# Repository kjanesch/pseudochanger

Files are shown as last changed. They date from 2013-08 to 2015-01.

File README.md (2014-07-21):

pseudochanger
=============
A project that aims to add an auxiliary input to head units that use the Panasonic variant of the Alpine MBus protocol.

Alpine MBus is a bidirectional one-wire serial interface used for communication between audio head units and peripherals like CD players, CD changers, and tape decks. A period for each bit is 3 ms, and low/high bits are indicated by how long the line is held low. Low for the first 600us indicates a 1, low for 1800 us indicates a 0. Data is a multiple of four bits, and a four-bit check follows the packet, an XOR of all the other 4-bit chunks.

The Panasonic variant uses different ping and ACK codes, sends some data at different times, and does what looks like type detection by sending out a cycle of codes. The included library reflects these differences.

This project was developed specifically for the 2002 Subaru WRX head unit, model CQ-EF7260A, and should work with other Panasonic head units that have the same 16-pin connector on the back, as also found in some Mazdas and Hondas.

This project contains:
 - Arduino MBusPanasonic library
   - Timing-driven bus interface
   - Sends static timestamp of Disc 1, Track 1, Time A:0A to indicate aux input 
 - Example implementation (pseudochanger)
   - Uses the Teensy branch of [finsprings/arduinaap](https://github.com/finsprings/arduinaap/tree/teensy) for the iPod Accessory Protocol interface.
 - Circuit and PCB diagrams
   - V1 is the handmade, free-handed version
   - V2 is the (incomplete) PCB of V1 with minor tweaks
   - V2.5 is a completely respun, integrated design
     - Built-in Atmega 32U4 (or 16U4 depending on code space needs)
     - Onboard switching regulator to generate 5V supply from +12V and accessory on/off
     - Smaller (0805/0603) SMT components
     - Ethernet jack for iPod connector
     - Op-amp based switch to make it solid state

TODO: 
 - Library:
   - Interrupt-driven approach to receiving and sending MBus data
   - Integrated polling routine to extract button presses
   - Fix issues with generating timestamps
   - Add a short example that doesn't keep state, switch between inputs, or control iPods (fewer I/Os, less setup, smaller code, no dependencies)
 - Implementation: 
   - Sort out why iPod interface doesn't work (Hardware? Software?)
 - EAGLE files:
   - Finish V2.5 PCB and BOM, construct boards IRL and test

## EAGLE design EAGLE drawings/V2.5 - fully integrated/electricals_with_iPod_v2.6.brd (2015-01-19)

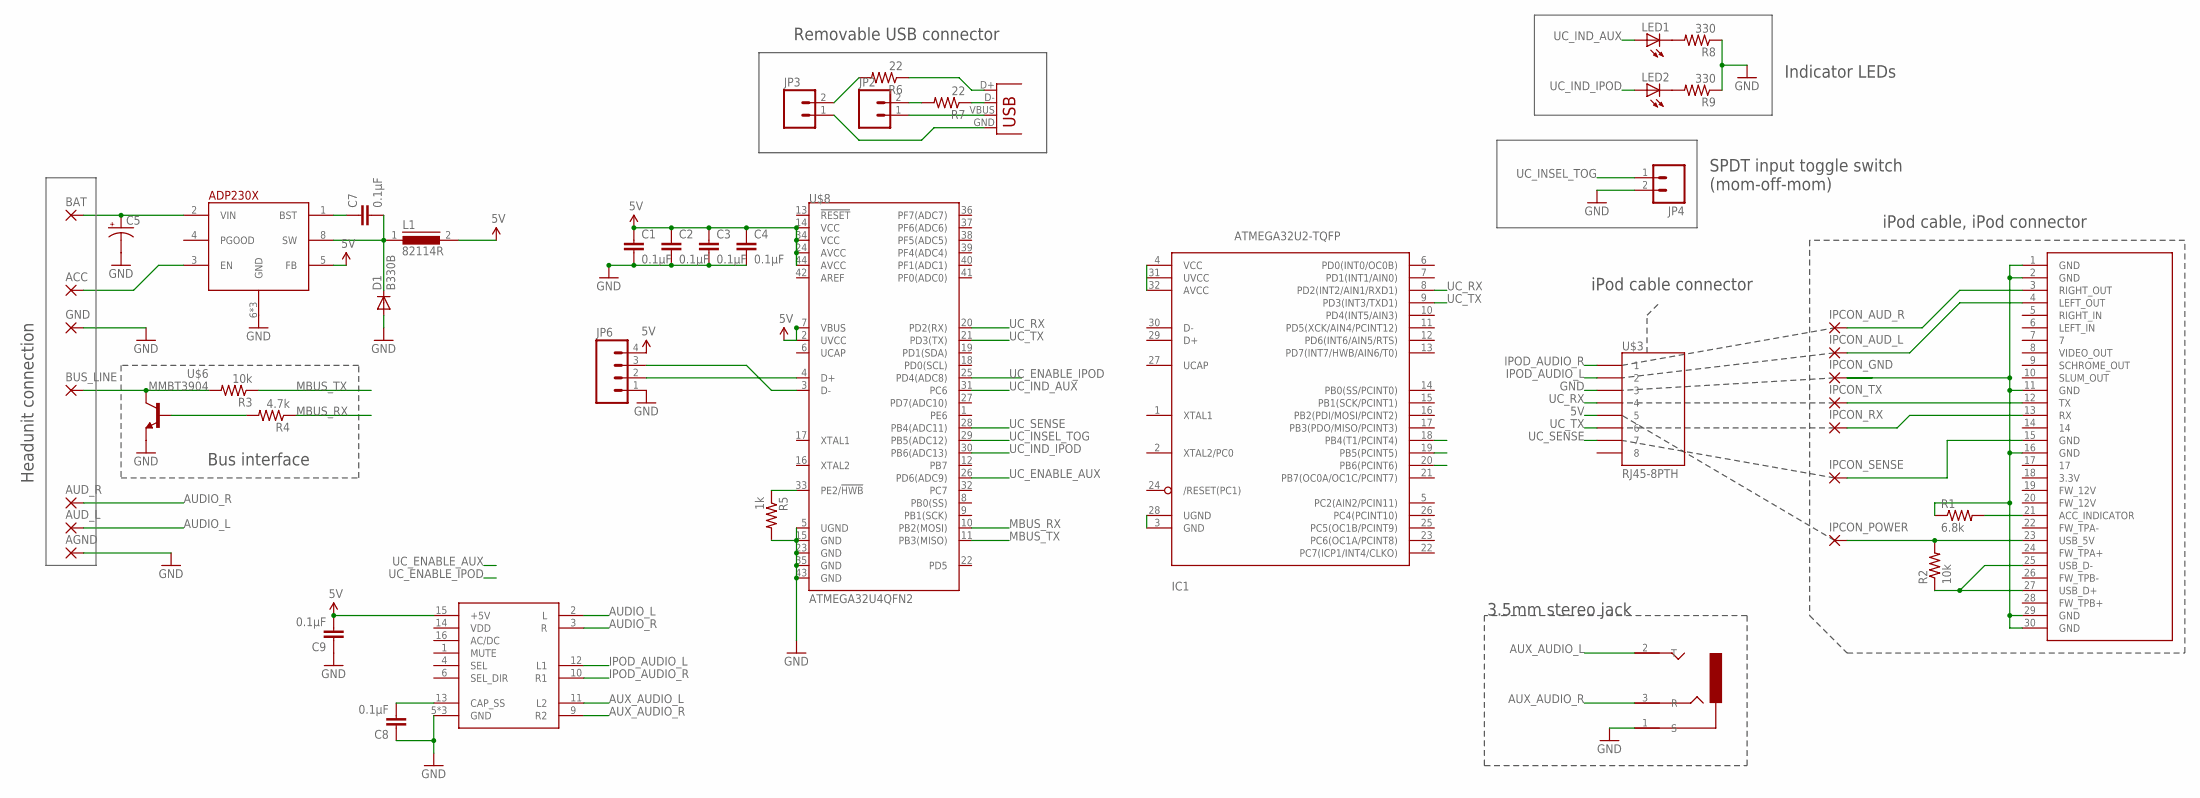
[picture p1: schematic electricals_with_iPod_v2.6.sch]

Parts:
ACC: 1,6/0,9
AGND: 1,6/0,9
AUD_L: 1,6/0,9
AUD_R: 1,6/0,9
BAT: 2,54/1,1
BUS_LINE: 1,6/0,9
C1, C2, C3, C4, C7, C8, C9: 0.1µF; 0603-CAP
C5: CAP_POLPTH2; CPOL-RADIAL-10UF-25V
D1: B330B; SMA-DIODE_ALT
GND: 2,54/1,1
IC1: ATMEGA32U2-TQFP; TQFP32-08
IPCON_AUD_L: 1,6/0,9
IPCON_AUD_R: 1,6/0,9
IPCON_GND: 1,6/0,9
IPCON_POWER: 1,6/0,9
IPCON_RX: 1,6/0,9
IPCON_SENSE: 1,6/0,9
IPCON_TX: 1,6/0,9
JP1: USBSMD; USB-MINIB
JP2, JP3: M02POGO_PIN_HOLES_ONLY; 1X02_PP_HOLES_ONLY
JP4: M02LOCK; 1X02_LOCK
JP6: M04PTH; 1X04
L1: 82114R
LED1, LED2: LED0603; LED-0603
R1: 6.8k; 0603-RES
R2, R3: 10k; 0603-RES
R4: 4.7k; 0603-RES
R5: 1k; 0603-RES
R6, R7: 22; 0603-RES
R8, R9: 330; 0603-RES
U$1: IPOD_CONNECTOR_MALE; IPOD_MALE_CONNECTOR
U$3: RJ45-8PTH; RJ45-8
U$5: ADP230X; SO8-THERM
U$6: MMBT3904; SOT23-3
U$7: STEREO_JACK_SJ1-353XNG3NG; 3.5MM_SJ1-353XNG
U$8: ATMEGA32U4QFN2; SPARKFUN-DIGITALIC_QFN-44-NOPAD
U$11: ISL54405IRTZ; QFN-16

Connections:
5V: C1.1, C2.1, C3.1, C4.1, C9.2, JP6.4, L1.2, U$3.5, U$5.5 (FB), U$8.2 (UVCC), U$8.7 (VBUS), U$8.14 (VCC), U$8.24 (AVCC), U$8.34 (VCC), U$8.44 (AVCC), U$11.15 (+5V)
AUDIO_L: AUD_L.1, U$11.2 (L)
AUDIO_R: AUD_R.1, U$11.3 (R)
AUX_AUDIO_L: U$7.2 (T), U$11.11 (L2)
AUX_AUDIO_R: U$7.3 (R), U$11.9 (R2)
GND: AGND.1, C1.2, C2.2, C3.2, C4.2, C5.2 (-), C8.1, C9.1, D1.A, GND.1, JP4.2, JP6.1, R5.2, R8.1, R9.1, U$3.3, U$5.6 (GND), U$5.7 (GND), U$5.PAD (GND), U$6.2 (E), U$7.1 (S), U$8.5 (UGND), U$8.15 (GND), U$8.23 (GND), U$8.35 (GND), U$8.43 (GND), U$11.5 (GND), U$11.7 (GND), U$11.8 (GND)
IPOD_AUDIO_L: U$3.2, U$11.12 (L1)
IPOD_AUDIO_R: U$3.1, U$11.10 (R1)
IP_GND: IPCON_GND.1, R1.1, U$1.1 (GND), U$1.2 (GND), U$1.11 (GND), U$1.16 (GND), U$1.29 (GND), U$1.30 (GND)
MBUS_RX: R4.1, U$8.10 (PB2(MOSI))
MBUS_TX: R3.1, U$8.11 (PB3(MISO))
unnamed: ACC.1, U$5.3 (EN)
unnamed: BAT.1, C5.1 (+), U$5.2 (VIN)
unnamed: C7.2, D1.C, L1.1, U$5.8 (SW)
unnamed: IPCON_POWER.1, R2.2, U$1.23 (USB_5V)
unnamed: C7.1, U$5.1 (BST)
unnamed: IPCON_SENSE.1, U$1.15 (GND)
unnamed: IPCON_RX.1, U$1.13 (RX)
unnamed: IPCON_TX.1, U$1.12 (TX)
unnamed: IPCON_AUD_R.1, U$1.3 (RIGHT_OUT)
unnamed: IPCON_AUD_L.1, U$1.4 (LEFT_OUT)
unnamed: R2.1, U$1.25 (USB_D-), U$1.27 (USB_D+)
unnamed: C8.2, U$11.13 (CAP_SS)
unnamed: R1.2, U$1.21 (ACC_INDICATOR)
unnamed: R5.1, U$8.33 (PE2/!HWB)
unnamed: LED1.C, R8.2
unnamed: LED2.C, R9.2
unnamed: IC1.3 (GND), IC1.28 (UGND)
unnamed: IC1.4 (VCC), IC1.32 (AVCC)
unnamed: BUS_LINE.1, R3.2, U$6.3 (C)
unnamed: R4.2, U$6.1 (B)
unnamed: JP1.D+, R6.1
unnamed: JP1.D-, R7.1
UC_ENABLE_AUX: U$8.26 (PD6(ADC9))
UC_ENABLE_IPOD: U$8.25 (PD4(ADC8))
UC_IND_AUX: LED1.A, U$8.31 (PC6)
UC_IND_IPOD: LED2.A, U$8.30 (PB6(ADC13))
UC_INSEL_TOG: JP4.1, U$8.29 (PB5(ADC12))
UC_RX: IC1.8 (PD2(INT2/AIN1/RXD1)), U$3.4, U$8.20 (PD2(RX))
UC_SENSE: U$3.7, U$8.28 (PB4(ADC11))
UC_TX: IC1.9 (PD3(INT3/TXD1)), U$3.6, U$8.21 (PD3(TX))
USB_BOB_D+: JP3.2, R6.2
USB_BOB_D-: JP2.2, R7.2
USB_BOB_GND: JP1.GND, JP3.1
USB_BOB_VBUS: JP1.VBUS, JP2.1
USB_D+: JP6.2, U$8.4 (D+)
USB_D-: JP6.3, U$8.3 (D-)

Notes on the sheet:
Bus interface
SPDT input toggle switch (mom-off-mom)
3.5mm stereo jack
Indicator LEDs
iPod cable, iPod connector
iPod cable connector
Headunit connection
Removable USB connector

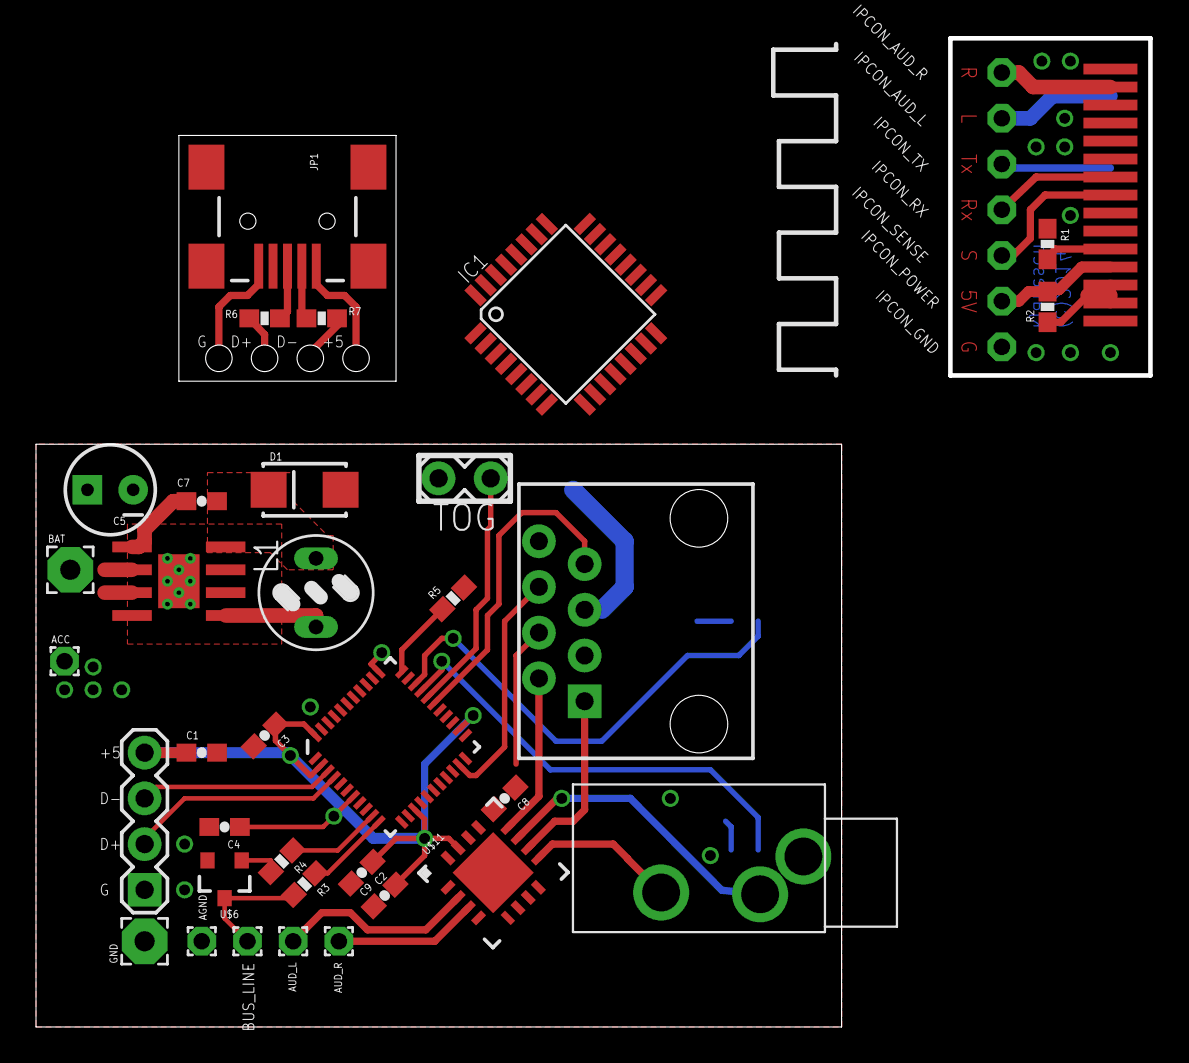
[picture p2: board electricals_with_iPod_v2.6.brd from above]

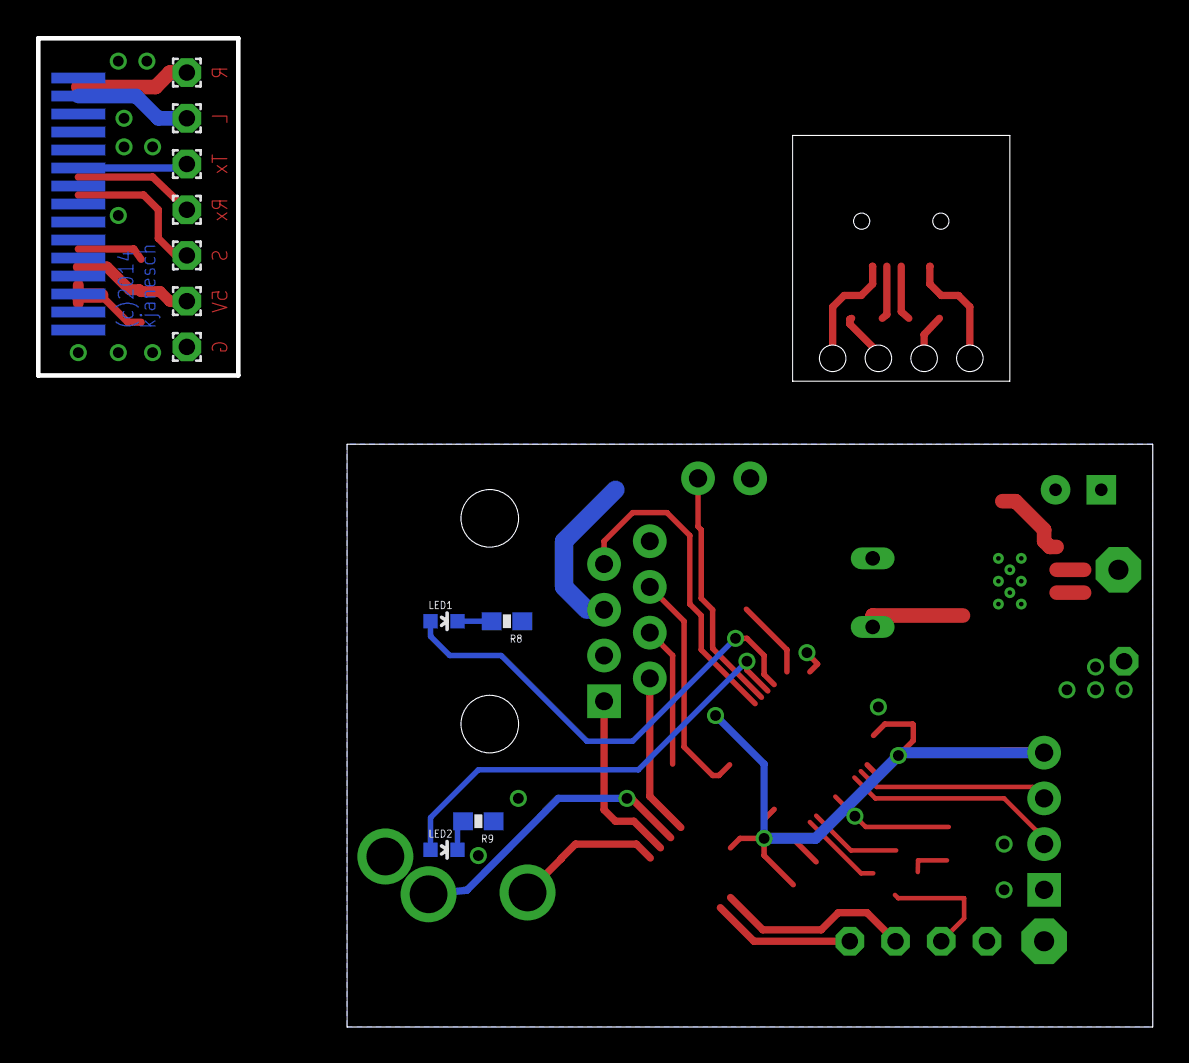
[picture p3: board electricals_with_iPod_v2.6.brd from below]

Board: 2 copper layers, 61.9 x 54.9 mm, 48 parts (12 on the bottom side), 45 nets.

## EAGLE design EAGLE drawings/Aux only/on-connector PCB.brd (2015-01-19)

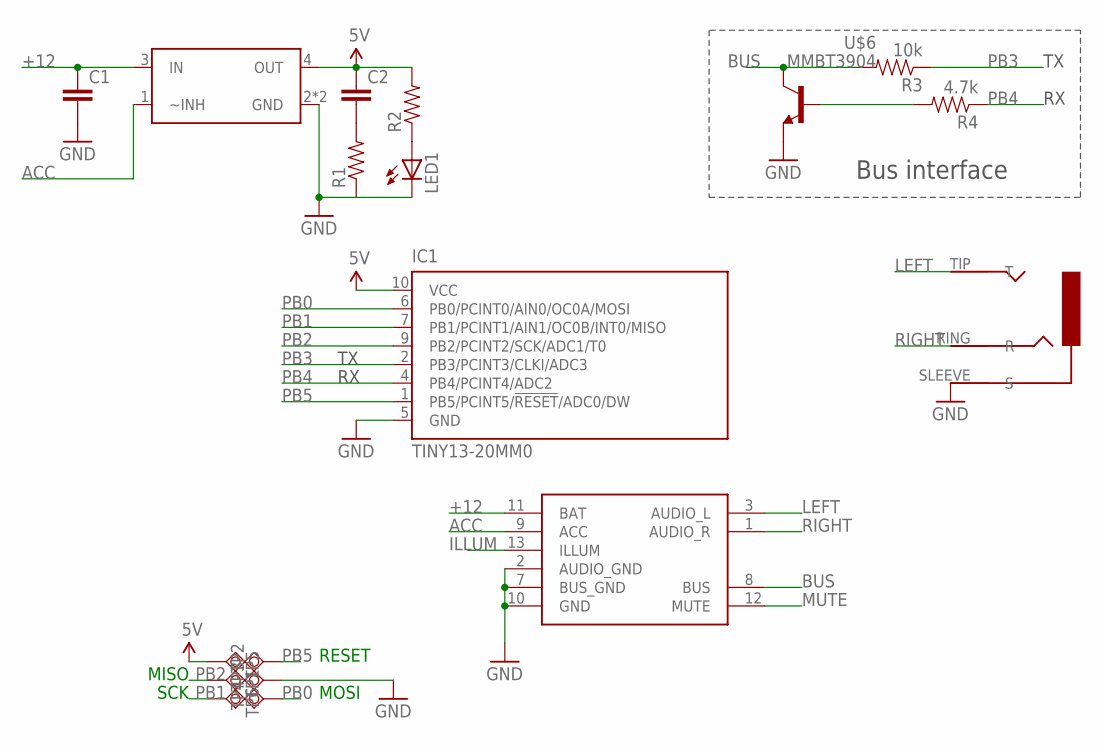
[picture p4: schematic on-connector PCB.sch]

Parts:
C1, C2: CAP0603-CAP; 0603-CAP
IC1: TINY13-20MM0; 10M1
LED1: LED0603; LED-0603
R1, R2: RESISTOR0603-RES; 0603-RES
R3: 10k; 0805
R4: 4.7k; 0805
TP1, TP2, TP3, TP4, TP6: TPSQTP07R; TP07R
TP5: TPSQTP07SQ; TP07SQ
U$1: PANASONIC_CN702_BACKBOARD; 040_MLCII_BACK_CN702
U$2: STEREO_JACK_SJ_352X; AUDIO-JACK-3.5MM-SMD
U$6: MMBT3904; SOT23-3
U$7: IFX20001; PG-SCT595-5

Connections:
5V: C2.1, IC1.10 (VCC), R2.2, TP5.TP, U$7.4 (OUT)
+12: C1.1, U$1.11 (BAT), U$7.3 (IN)
ACC: U$1.9 (ACC), U$7.1 (~INH)
BUS: R3.2, U$1.8 (BUS), U$6.3 (C)
GND: C1.2, IC1.5 (GND), IC1.11 (GND), LED1.C, R1.1, TP3.TP, U$1.2 (AUDIO_GND), U$1.7 (BUS_GND), U$1.10 (GND), U$2.SLEEVE (S), U$6.2 (E), U$7.2 (GND), U$7.5 (GND)
ILLUM: U$1.13 (ILLUM)
LEFT: U$1.3 (AUDIO_L), U$2.TIP (T)
MUTE: U$1.12 (MUTE)
unnamed: C2.2, R1.2
unnamed: LED1.A, R2.1
unnamed: R4.2, U$6.1 (B)
PB0: IC1.6 (PB0/PCINT0/AIN0/OC0A/MOSI), TP4.TP
PB1: IC1.7 (PB1/PCINT1/AIN1/OC0B/INT0/MISO), TP6.TP
PB2: IC1.9 (PB2/PCINT2/SCK/ADC1/T0), TP1.TP
PB3: IC1.2 (PB3/PCINT3/CLKI/ADC3), R3.1
PB4: IC1.4 (PB4/PCINT4/ADC2), R4.1
PB5: IC1.1 (PB5/PCINT5/!RESET!/ADC0/DW), TP2.TP
RIGHT: U$1.1 (AUDIO_R), U$2.RING (R)

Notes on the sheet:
Bus interface
MOSI
MISO
SCK
RESET

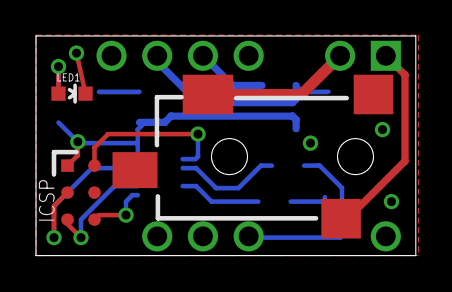
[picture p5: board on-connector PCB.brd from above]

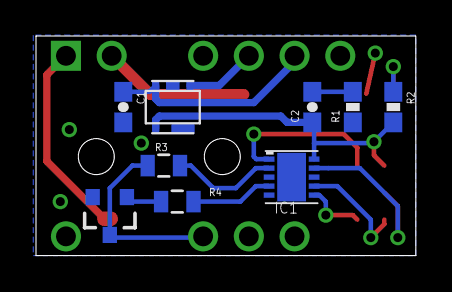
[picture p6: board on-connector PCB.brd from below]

Board: 2 copper layers, 21.1 x 12.2 mm, 18 parts (9 on the bottom side), 16 nets.

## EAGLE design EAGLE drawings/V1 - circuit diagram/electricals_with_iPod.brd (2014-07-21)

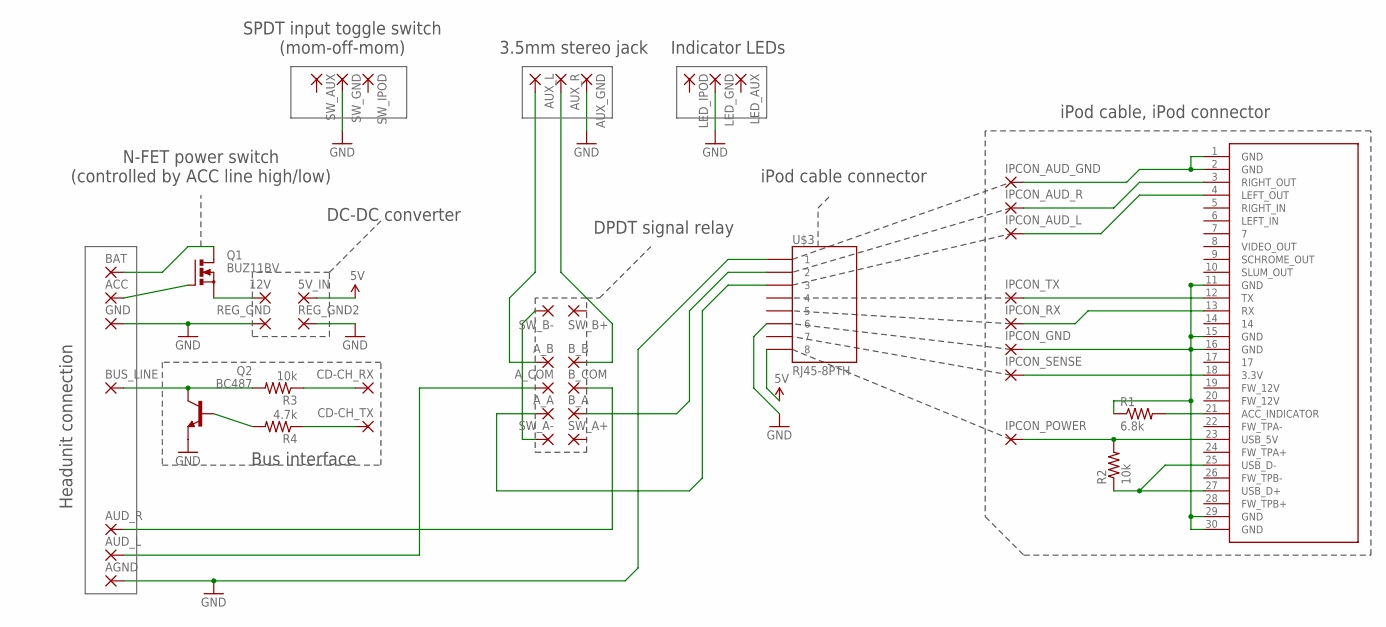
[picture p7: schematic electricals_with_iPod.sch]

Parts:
5V_IN, 12V: 2,54/1,1
ACC: 1,6/0,9
AGND: 1,6/0,9
AUD_L: 1,6/0,9
AUD_R: 1,6/0,9
AUX_GND: 1,6/0,9
AUX_L: 1,6/0,9
AUX_R: 1,6/0,9
A_A: 1,6/0,9
A_B: 1,6/0,9
A_COM: 1,6/0,9
BAT: 2,54/1,1
BUS_LINE: 1,6/0,9
B_A: 1,6/0,9
B_B: 1,6/0,9
B_COM: 1,6/0,9
CD-CH_RX: 1,6/0,9
CD-CH_TX: 1,6/0,9
GND: 2,54/1,1
IPCON_AUD_GND: 1,6/0,9
IPCON_AUD_L: 1,6/0,9
IPCON_AUD_R: 1,6/0,9
IPCON_GND: 1,6/0,9
IPCON_POWER: 1,6/0,9
IPCON_RX: 1,6/0,9
IPCON_SENSE: 1,6/0,9
IPCON_TX: 1,6/0,9
LED_AUX: 1,6/0,9
LED_GND: 1,6/0,9
LED_IPOD: 1,6/0,9
Q1: BUZ11BV; TO220BV
Q2: BC487; TO92-EBC
R1: 6.8k; 1206
R2, R3: 10k; 1206
R4: 4.7k; 1206
REG_GND, REG_GND2: 2,54/1,1
SW_A+: 1,6/0,9
SW_A-: 1,6/0,9
SW_AUX: 1,6/0,9
SW_B+: 1,6/0,9
SW_B-: 1,6/0,9
SW_GND: 1,6/0,9
SW_IPOD: 1,6/0,9
U$1: IPOD_CONNECTOR_MALE; IPOD_MALE_CONNECTOR
U$3: RJ45-8PTH; RJ45-8

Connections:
5V: 5V_IN.1, U$3.8
GND: AGND.1, AUX_GND.1, GND.1, LED_GND.1, Q2.E, REG_GND.1, REG_GND2.1, SW_GND.1, U$3.1, U$3.6
unnamed: ACC.1, Q1.G
unnamed: BAT.1, Q1.D
unnamed: 12V.1, Q1.S
unnamed: IPCON_POWER.1, R2.2, U$1.23 (USB_5V)
unnamed: IPCON_AUD_GND.1, U$1.1 (GND), U$1.2 (GND)
unnamed: IPCON_SENSE.1, U$1.18 (3.3V)
unnamed: IPCON_RX.1, U$1.13 (RX)
unnamed: IPCON_TX.1, U$1.12 (TX)
unnamed: IPCON_AUD_R.1, U$1.3 (RIGHT_OUT)
unnamed: IPCON_AUD_L.1, U$1.4 (LEFT_OUT)
unnamed: R2.1, U$1.25 (USB_D-), U$1.27 (USB_D+)
unnamed: IPCON_GND.1, R1.1, U$1.11 (GND), U$1.15 (GND), U$1.16 (GND), U$1.29 (GND), U$1.30 (GND)
unnamed: R1.2, U$1.21 (ACC_INDICATOR)
unnamed: SW_A-.1, SW_B-.1
unnamed: AUD_L.1, A_COM.1
unnamed: AUD_R.1, B_COM.1
unnamed: AUX_L.1, A_B.1
unnamed: AUX_R.1, B_B.1
unnamed: BUS_LINE.1, Q2.C, R3.2
unnamed: Q2.B, R4.2
unnamed: CD-CH_RX.1, R3.1
unnamed: CD-CH_TX.1, R4.1
unnamed: B_A.1, U$3.2
unnamed: A_A.1, U$3.3

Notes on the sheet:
Bus interface
N-FET power switch (controlled by ACC line high/low)
DC-DC converter
SPDT input toggle switch (mom-off-mom)
3.5mm stereo jack
Indicator LEDs
iPod cable, iPod connector
iPod cable connector
DPDT signal relay
Headunit connection

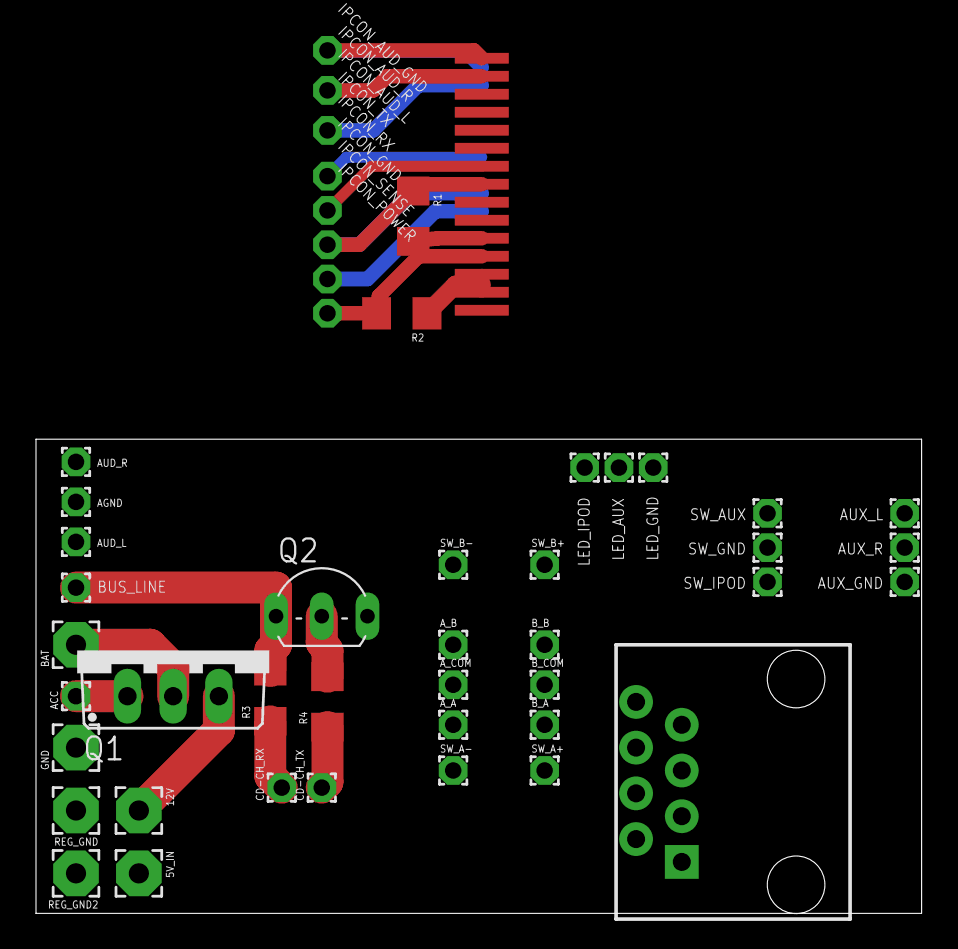
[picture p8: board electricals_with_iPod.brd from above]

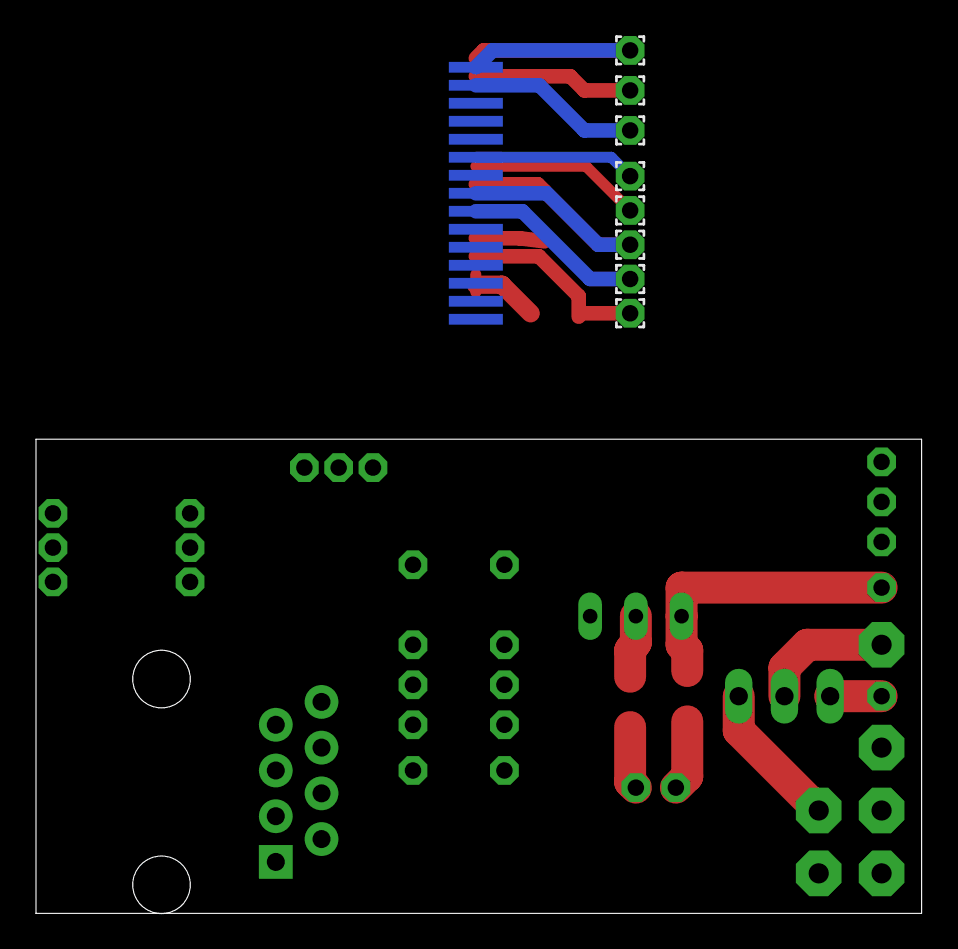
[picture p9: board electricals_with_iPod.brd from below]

Board: 2 copper layers, 49.2 x 26.3 mm, 48 parts (9 on the bottom side), 26 nets.

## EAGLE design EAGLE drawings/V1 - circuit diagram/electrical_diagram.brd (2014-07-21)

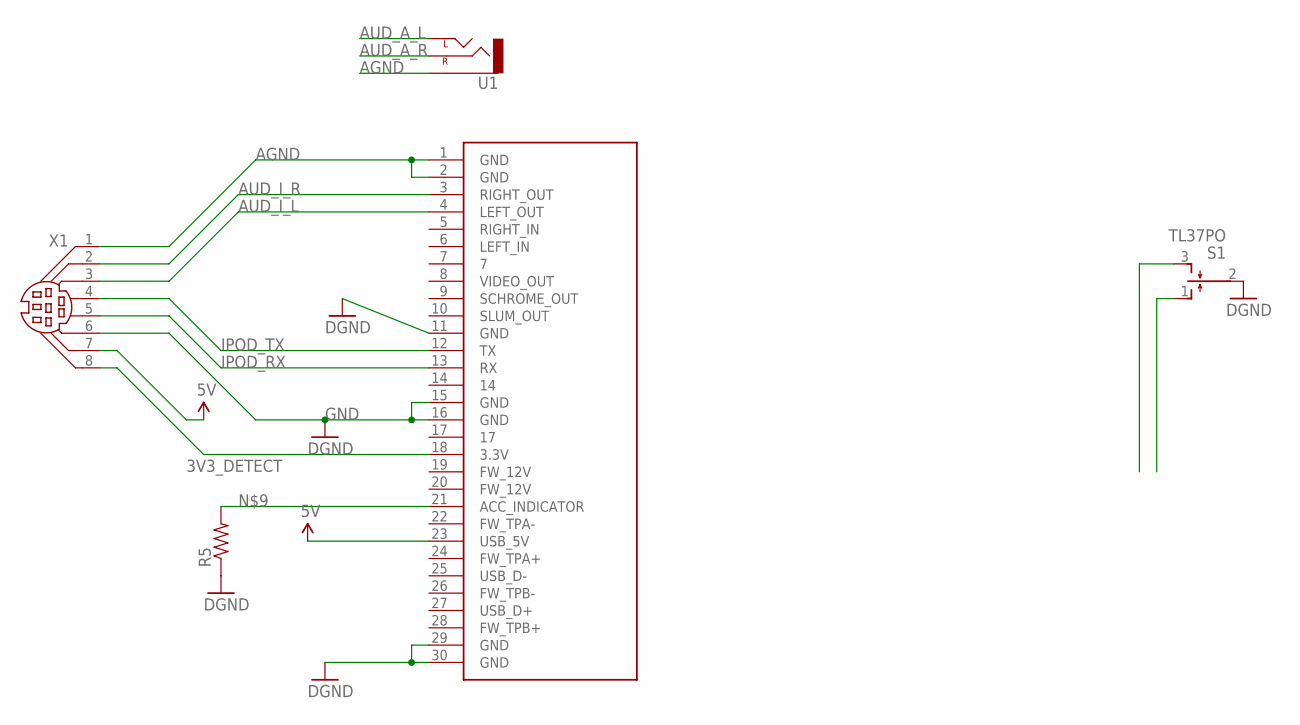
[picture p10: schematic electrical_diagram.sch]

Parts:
R5: RESISTOR0805-RES; 0805
S1: TL37PO; TL3XPO
U1: AUDIO-JACKSMD2; AUDIO-JACK-3.5MM-SMD
U$1: IPOD_CONNECTOR_MALE; IPOD_MALE_CONNECTOR
X1: MDIN08K

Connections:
3V3_DETECT: U$1.18 (3.3V), X1.8
5V: U$1.23 (USB_5V), X1.7
AGND: U1.SLEEVE, U$1.1 (GND), U$1.2 (GND), X1.1
AUD_A_L: U1.TIP (LEFT)
AUD_A_R: U1.RING (RIGHT)
AUD_I_L: U$1.4 (LEFT_OUT), X1.3
AUD_I_R: U$1.3 (RIGHT_OUT), X1.2
GND: R5.1, S1.2, U$1.11 (GND), U$1.15 (GND), U$1.16 (GND), U$1.29 (GND), U$1.30 (GND), X1.6
IPOD_RX: U$1.13 (RX), X1.5
IPOD_TX: U$1.12 (TX), X1.4
unnamed: R5.2, U$1.21 (ACC_INDICATOR)

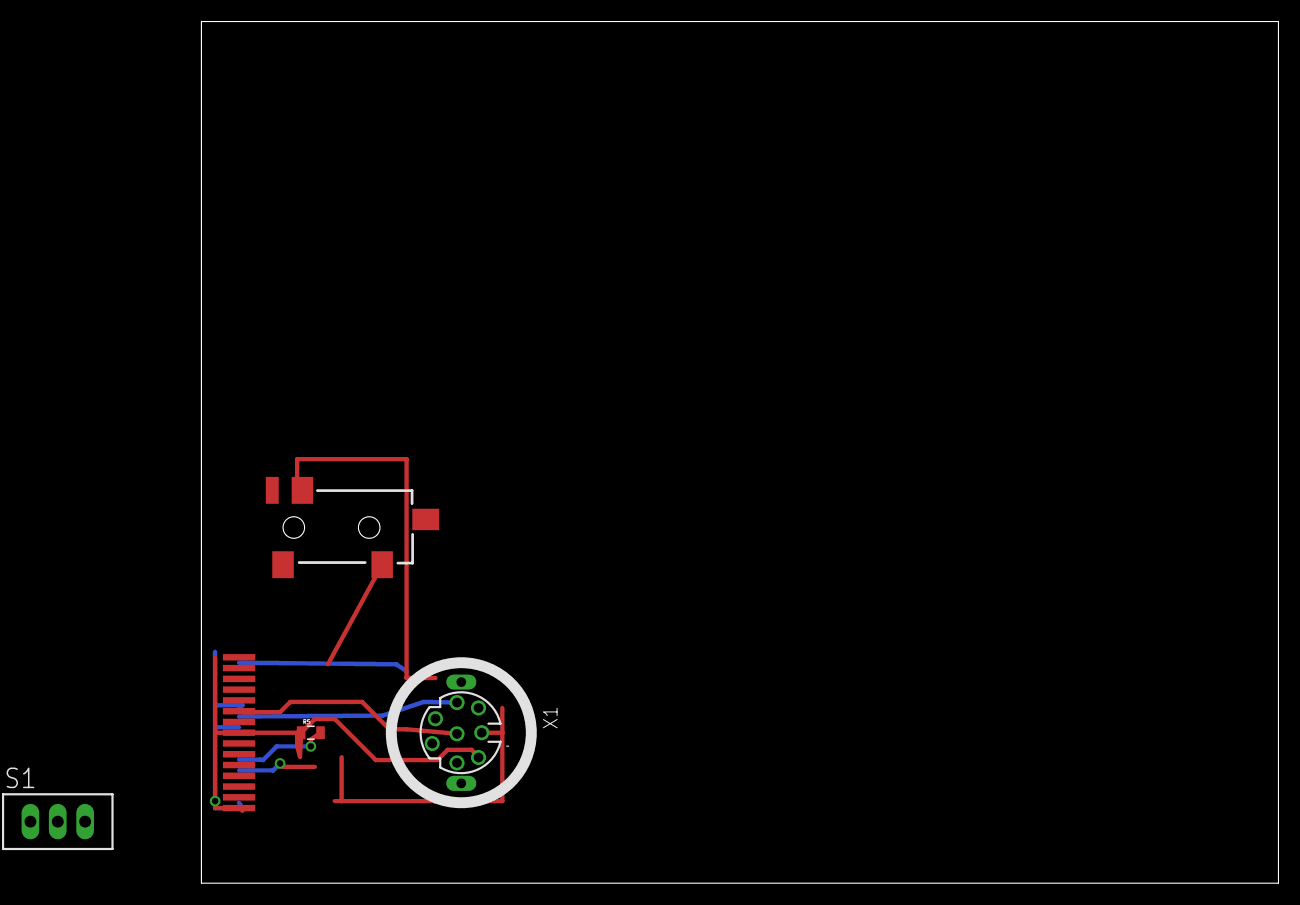
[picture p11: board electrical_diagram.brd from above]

Board: 2 copper layers, 100.0 x 80.0 mm, 5 parts (0 on the bottom side), 9 nets.

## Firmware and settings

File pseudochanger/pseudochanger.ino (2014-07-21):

#include <AdvancedRemote.h>
#include <MBusPanasonic.h>

//#define IPOD_SERIAL_DEBUG
#define DEBUG_MODE
//#define DISABLE_RELAY

//playback state definitions
#define IPOD_ACTIVE 1
#define AUX_ACTIVE  2
#define MBUS_DELAY 7

#define mBusIn  PIN_D1
#define mBusOut PIN_D0

//pin definitions
static const byte SENSE_IPOD  = PIN_F4;
static const byte LED_AUX     = PIN_C6;
static const byte LED_IPOD    = PIN_C7;
static const byte RELAY_AUX   = PIN_B0;
static const byte RELAY_IPOD  = PIN_B1;
static const byte TOGGLE_AUX  = PIN_D5;
static const byte TOGGLE_IPOD = PIN_D4;

byte activeInput;

boolean ipodAvailable = false;

MBus mBus(mBusIn, mBusOut);

//HardwareSerial uart = HardwareSerial();
AdvancedRemote ipod = AdvancedRemote(Serial1);

byte playbackStatus = STOPPED;
boolean updateDisplay = false;

unsigned long plistindex = 1;
unsigned long trackindex = 1;

unsigned long playtime = 0;
unsigned long plistcount = 0;
unsigned long trackcount = 0;

uint64_t mbusMsg = 0ULL;
uint64_t nextUpdate = 0;
uint64_t prevPing   = 0;

uint32_t tmp = 0;

/// iPod AdvancedRemote callbacks ////////////////////////////////////
void shuffleModeHandler(AdvancedRemote::ShuffleMode mode){
  switch(mode){
  case AdvancedRemote::SHUFFLE_MODE_OFF:
    Serial.println("shuffle off");
    playbackStatus &= ~SHUFFLE_MASK;
    break;
  case AdvancedRemote::SHUFFLE_MODE_SONGS:
    Serial.println("shuffle songs");
    playbackStatus =  ((~SHUFFLE_MASK)&playbackStatus)| SHUFFLE_SONGS;
    break;
  case AdvancedRemote::SHUFFLE_MODE_ALBUMS:
    Serial.println("shuffle off");
    playbackStatus =  ((~SHUFFLE_MASK)&playbackStatus)| SHUFFLE_ALBUMS;
    break;
  }
}

void repeatModeHandler(AdvancedRemote::RepeatMode mode){
  switch(mode){
  case AdvancedRemote::REPEAT_MODE_OFF:
    Serial.println("repeat off");
    playbackStatus &= ~REPEAT_MASK;
    break;
  case AdvancedRemote::REPEAT_MODE_ONE_SONG:
    Serial.println("repeat one");
    playbackStatus =  ((~REPEAT_MASK)&playbackStatus)| REPEAT_ONE;
    break;
  case AdvancedRemote::REPEAT_MODE_ALL_SONGS:
    Serial.println("repeat all");
    playbackStatus =  ((~REPEAT_MASK)&playbackStatus)| REPEAT_ALL;
    break;
  }
}

void playlistPositionHandler(unsigned long playlistPosition){
  trackindex = playlistPosition;
}

void currentPlaylistSongCountHandler(unsigned long count){
  plistcount = count;
}

void pollingHandler(AdvancedRemote::PollingCommand command, unsigned long playlistPositionOrelapsedTimeMs){
  switch(command){
  // track change. 'val' is the playlist position
  case AdvancedRemote::POLLING_TRACK_CHANGE: 
    trackindex = playlistPositionOrelapsedTimeMs;
    Serial.print("Track changed to index ");
    Serial.println(playlistPositionOrelapsedTimeMs, DEC);
    break;

  // elapsed time. 'val' is song playback time in ms
  case AdvancedRemote::POLLING_ELAPSED_TIME:
    playtime = playlistPositionOrelapsedTimeMs/1000;
    Serial.print("track elapsed time is ");
    Serial.println(playtime, DEC);
    break;

  default:
    break;
  }
}
#ifdef DEBUG_MODE
void iPodNameHandler(const char *ipodName){
    Serial.print("\tiPod name\t"); Serial.println(ipodName);  
}
#endif


void setup(){
  ioinit();
  Serial.begin(9600); //12 Mbps, regardless of speed
  //uart.begin(iPodSerial::IPOD_SERIAL_RATE);
  //ipod.setSerial(uart);
  //ipod.set
  
  //ipod.setFeedbackHandler(feedbackHandler);
  ipod.setShuffleModeHandler(shuffleModeHandler);
  ipod.setRepeatModeHandler(repeatModeHandler);
  ipod.setPollingHandler(pollingHandler);
  ipod.setPlaylistPositionHandler(playlistPositionHandler);
  ipod.setCurrentPlaylistSongCountHandler(currentPlaylistSongCountHandler);
#ifdef DEBUG_MODE
  //ipod.setDebugPrint();
  ipod.setiPodNameHandler(iPodNameHandler);
#endif
#ifdef IPOD_SERIAL_DEBUG
  setDebugPrint(Serial);
  setLogPrint(Serial);
#endif
  ipod.setup();
  ipod.enable();
}

void loop(){
  ipod.loop();
  switcher();
  if(!ipodAvailable && digitalRead(SENSE_IPOD) == 0)
    ipodAvailable = true;
  else
    ipodAvailable = false;
  
  if(updateDisplay || (playbackStatus&PLAYING && activeInput == AUX_ACTIVE && nextUpdate<millis())){
    digitalWrite(PIN_D6, ~digitalRead(PIN_D6));
    //mBus.sendPlayingTrack(plistindex, trackindex, playtime, playbackStatus);
    mBus.send(0xE9401010A0A0002ull);
    updateDisplay = false;
    
    nextUpdate=millis()+500;
  }
  
#ifdef DEBUG_MODE
  else if(nextUpdate<millis()){
    Serial.print("\nDEBUG\n\tplayback status\t"); Serial.println(playbackStatus, BIN);
    Serial.print("\tinput\t"); 
    if(activeInput==IPOD_ACTIVE) Serial.println("iPod");
    else Serial.println("aux");
    Serial.print("\tipodAvailable\t"); Serial.println(ipodAvailable, BIN);
    
    Serial.print("\tplistindex\t"); Serial.println(plistindex);
    Serial.print("\ttrackindex\t"); Serial.println(trackindex);
    Serial.print("\tplaytime\t"); Serial.println(playtime);
    Serial.print("\tplistcount\t"); Serial.println(plistcount);
    Serial.print("\ttrackcount\t"); Serial.println(trackcount);

    if(ipodAvailable || activeInput==IPOD_ACTIVE){
       ipod.getiPodName(); //sent to iPodNameHandler
      Serial.print("\trequesting iPod state\t"); ipod.getTimeAndStatusInfo(); //sent to PlaylistPositionHandler
      
    }

    nextUpdate=millis()+2000;
  }
#endif

  if(mBus.receive(&mbusMsg)){
    
    if(mbusMsg == 0x68){
      if(millis()-prevPing<1500){
        Serial.println("INFO: pings too fast, pausing.");
        playbackStatus = playbackStatus & (~PBSTATUS_MASK);
        playbackStatus |= PAUSED;
      }
      else{
        Serial.print("  HU: ping;  PBStatus: ");
        Serial.println(playbackStatus, HEX);
        delay(MBUS_DELAY);
        mBus.send(0xE8);
        delay(MBUS_DELAY);
        if(playbackStatus & PAUSED || (playbackStatus & PBSTATUS_MASK) == STOPPED){
          mBus.send(0x69);
          delay(MBUS_DELAY);
          //Serial.println("\t\t\tresend CD status");
          mBus.send(0xEF00000);
          delay(MBUS_DELAY);
          mBus.sendChangedCD(plistindex,trackindex);
          delay(MBUS_DELAY);
          mBus.sendCDStatus(plistindex);
          delay(MBUS_DELAY);
          if(activeInput==IPOD_ACTIVE)
            //mBus.sendPlayingTrack(plistindex, trackindex, playtime, playbackStatus);
            mBus.send(0xE930101AA000009ull);
          else
            mBus.send(0xE930601000A0009ULL);
        }
        else if(playbackStatus&PLAYING){
          mBus.send(0x78);
        }
        prevPing = millis();
      }
    }
    else if((uint64_t)(mbusMsg&MBUS_CMD_MASK) == MBUS_CMD){
      mBus.send(MBUS_DELAY);
      Serial.print("  HU: P/B state change -- ");
      switch(mbusMsg & 0xFFFull){
        case MBUS_CMD_PLAY:
          Serial.println("play");
          if(activeInput & IPOD_ACTIVE){
        
          }
          else{

            changePBStatus(PLAYING|REPEAT_ALL|SHUFFLE_SONGS);
          }  
          break;
        case MBUS_CMD_PAUSE:
          Serial.println("pause");
          if(activeInput & IPOD_ACTIVE){
          }
          else{
            //clear current state
            
            changePBStatus(PAUSED);
          }
          break;
        case MBUS_CMD_FFWD:
          Serial.println("ffwd");
          break;
        case MBUS_CMD_RWD:
          Serial.println("rew");
          break;
        default:
          Serial.println("??");
          break;
      }
      delay(MBUS_DELAY);
      mBus.sendPlayingTrack(plistindex, trackindex, playtime, playbackStatus);
      Serial.print("P/BS: ");
      Serial.println(playbackStatus, HEX);
    }
    else if((uint64_t)(mbusMsg&MBUS_SELCMD_MASK) == MBUS_SELCMD){
      Serial.print("  HU: select -- disc ");
      tmp = (mbusMsg & MBUS_SELCMD_DISCMASK)>>12;
      Serial.print(tmp, HEX);     
      
      tmp = (mbusMsg & MBUS_SELCMD_TRACKMASK)>>4;
      
      Serial.print(", track ");
      Serial.println(tmp, HEX);     
    }
    else if((uint64_t)(mbusMsg&MBUS_PBMODE_MASK) == MBUS_PBMODE){
      Serial.print("  HU: P/B mode change -- ");
      //switch(mbusMsg & ~MBUS_PBMODE_MASK){
        
        
        
      //}
    }
  }
}

void changePBStatus(uint8_t newstate){
  //clear any states that are being changed
  if(newstate & PBSTATUS_MASK)
    playbackStatus = playbackStatus & (~PBSTATUS_MASK);
  if(newstate & SHUFFLE_MASK)
    playbackStatus = playbackStatus & (PBSTATUS_MASK | REPEAT_MASK);
  if(newstate & REPEAT_MASK)
    playbackStatus = playbackStatus & (PBSTATUS_MASK | SHUFFLE_MASK);

  playbackStatus |= newstate;  
}
/* also useful iPod commands
getShuffleMode();
setShuffleMode(AdvancedRemote::SHUFFLE_MODE_ [OFF, SONGS, ALBUMS]  );

getRepeatMode();
setRepeatMode(AdvancedRemote::REPEAT_MODE_ [OFF, ONE_SONG, ALL_SONGS]);

switchToItem(AdvancedPlaylist::ITEM_ , ulong index);
//                                  PLAYLIST
//                                  ARTIST
//                                  ALBUM
//                                  GENRE
//                                  SONG
//                                  COMPOSER

switchToMainLibraryPlaylist();
executeSwitch(ulong index); //0xFFFFFFFF is always beginning of playlist

controlPlayback(AdvancedRemote::PLAYBACK_CONTROL_ );
//                                               PLAY_PAUSE
//                                               STOP
//                                               SKIP_FORWARD
//                                               SKIP_BACKWARD
//                                               FAST_FORWARD
//                                               FAST_REVERSE
//                                               STOP_FF_OR_REV
*/

//the code to switch inputs. handles toggling ipod play/pause, relay, lights, etc.
void switcher(){
  if(!digitalRead(TOGGLE_IPOD) && activeInput == AUX_ACTIVE && ipodAvailable){
    Serial.println("switching to iPod");
    //mbus.sendswitchingstatus(ipod); //send "AA00" or something
    mBus.send(0xE9300010A000009ULL);
    digitalWrite(LED_AUX,  0);
    digitalWrite(LED_IPOD, 1);
#ifndef DISABLE_RELAY
    digitalWrite(RELAY_IPOD, 1);
    delay(2);
    digitalWrite(RELAY_IPOD, 0);
#endif
    activeInput = IPOD_ACTIVE;
    
    //pause iPod if it's playing
    if(ipodAvailable && playbackStatus&PLAYING){
      ipod.enable();
      ipod.setPollingMode(AdvancedRemote::POLLING_START);
      ipod.controlPlayback(AdvancedRemote::PLAYBACK_CONTROL_PLAY_PAUSE);
      playbackStatus = (playbackStatus & (~PBSTATUS_MASK)) | PLAYING;
    }
  }
  else if(!digitalRead(TOGGLE_AUX) && activeInput == IPOD_ACTIVE){
    Serial.println("switching to aux");
    //mbus.sendswitchingstatus(AUX);
    mBus.send(0xE930001AAAA0009ULL);
    digitalWrite(LED_AUX,  1);
    digitalWrite(LED_IPOD, 0);
#ifndef DISABLE_RELAY
    digitalWrite(RELAY_AUX, 1);
    delay(2);
    digitalWrite(RELAY_AUX, 0);
#endif
    activeInput = AUX_ACTIVE;
    
    //pause iPod if it's playing
    if(ipodAvailable && playbackStatus&PLAYING){
      ipod.controlPlayback(AdvancedRemote::PLAYBACK_CONTROL_PLAY_PAUSE);
      ipod.setPollingMode(AdvancedRemote::POLLING_STOP);
      playbackStatus = (playbackStatus & (~PBSTATUS_MASK)) | PAUSED;
      ipod.disable();
    }
  }
}


//set up pin directions and re-set the relay to auxin
void ioinit(){
  pinMode(LED_AUX, OUTPUT); // aux led
  pinMode(LED_IPOD, OUTPUT); // ipod led
  pinMode(RELAY_AUX, OUTPUT); // relay, switch to aux
  pinMode(RELAY_IPOD, OUTPUT); // relay, switch to ipod
  digitalWrite(RELAY_AUX,  0);
  digitalWrite(RELAY_IPOD, 0);
  digitalWrite(LED_AUX,    1);
  digitalWrite(LED_IPOD,   0);
  
  pinMode(TOGGLE_AUX,  INPUT_PULLUP); // toggle, aux
  pinMode(TOGGLE_IPOD, INPUT_PULLUP); // toggle, ipod
  pinMode(SENSE_IPOD, INPUT_PULLUP);
  
  //set the input to the aux by default until an iPod is detected
#ifndef DISABLE_RELAY
  digitalWrite(RELAY_AUX, 1);
  delay(2);
  digitalWrite(RELAY_AUX, 0);
#endif
  activeInput = AUX_ACTIVE;
}

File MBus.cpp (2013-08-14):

/***
 * MBus.h - Library to emulate Alpine M-Bus commands
 * 
 * Copyright 2012 Oliver Mueller
 * 
 * Licensed under the Apache License, Version 2.0 (the "License");
 * you may not use this file except in compliance with the License.
 * You may obtain a copy of the License at
 * 
 * http://www.apache.org/licenses/LICENSE-2.0
 * 
 * Unless required by applicable law or agreed to in writing, software
 * distributed under the License is distributed on an "AS IS" BASIS,
 * WITHOUT WARRANTIES OR CONDITIONS OF ANY KIND, either express or implied.
 * See the License for the specific language governing permissions and
 * limitations under the License.
 ***/
#include "./MBus.h"
#include <stdio.h>

char buffer[30];

MBus::MBus(uint8_t in, uint8_t out){

  _in=in;
  _out=out;
  
  _playerstate = PAUSED;

  pinMode(_in, INPUT);
  pinMode(_out,OUTPUT);
}

void MBus::sendZero(){
  digitalWrite(_out, HIGH);
  delayMicroseconds(600);
  digitalWrite(_out, LOW);
  delayMicroseconds(2400);
}

void MBus::sendOne(){
  digitalWrite(_out, HIGH);
  delayMicroseconds(1800);
  digitalWrite(_out, LOW);
  delayMicroseconds(1200);
}

void MBus::writeHexBitWise(uint8_t message){
  for(int8_t i=3; i>-1; i--){
    uint8_t output=((message & (1<<i) )>>i);
    if(output==1)
      sendOne();
    else
      sendZero();
  }
}

boolean MBus::checkParity(uint64_t *message){
  uint8_t parity=0;
  uint8_t test=0;
  for(uint8_t i=16; i>0; i--){
    test=((*message & ((uint64_t)0xF<<i*4) )>>i*4);
    parity=parity^test;
  }
  parity+=1;

  if(parity==(*message & ((uint64_t)0xF)))
    return true;
  else
    return false;
}

void MBus::send(uint64_t message){
  uint8_t printed=0;
  uint8_t parity=0;
  digitalWrite(11, HIGH);
  for(int8_t i=16; i>=0; i--){
    uint8_t output=((message & ((uint64_t)0xF<<i*4) )>>i*4);
    parity=parity^output;
    if(!output&&!printed){
      //do nothing
    }
    else{
      writeHexBitWise(output);
      printed++;
    }
  }
  parity = (parity+1)&0x0F;
  writeHexBitWise(parity);
  if(Serial){
    Serial.print("\tOUT:\t0x");
    if(printed>7)
      Serial.print((long)(message>>32), HEX);
    Serial.print((long)message, HEX);
    //sprintf(buffer, "\tOUT:\t%8x%8x", (unsigned long)(message>>32), (unsigned long)message);
    //sprintf(buffer, "\tOUT:\t%16x %1x", message, parity);//);
    //Serial.println(buffer);
    //Serial.print((unsigned long long)message, HEX);
    
    Serial.print(" ");
    Serial.println(parity, HEX);
  }
  digitalWrite(11, LOW);
}

boolean MBus::receive(uint64_t *message){
  *message=0;
  if(digitalRead(_in)==LOW){
    unsigned long time=micros();

    boolean gelesen=false; 
    uint8_t counter=0;

    while((micros()-time)<4000){
      if(digitalRead(_in)==HIGH&&!gelesen){
        if((micros()-time)<1400&&(micros()-time)>600){//0 is in between 600 and 1700 microseconds
          *message*=2;
          counter++;
          gelesen=true; 
        }
        else if((micros()-time)>1400){//1 is longer then 1700 microseconds
          *message*=2;
          *message+=1;
          counter++;
          gelesen=true;
        }
      }
      if(gelesen&&digitalRead(_in)==LOW){
        gelesen=false;
        time=micros();
      }  
    }
    if(counter%4||!checkParity(message)||counter==0){
      //message is not ok
      *message=0;
      return false;
    }
    else{
      if(Serial && !(*message==0x28B || *message==0x38C || *message==0x48D || *message==0x58E)){
        Serial.print("\t IN:\t0x");
        if(counter>31)
          Serial.print((long unsigned int)((*message)>>32), HEX);
        Serial.println((long unsigned int)(*message), HEX);
        //sprintf(buffer, "\t IN:\t %16x", (uint64_t)*message);//);
        //Serial.println(buffer);
      }
      (*message)=(*message)>>4;//ingnore parity
      return true;
    }
  }
  return false;

}

/*
 CD-changer emulation from here on
 */
void MBus::sendPlayingTrack(uint8_t disc, uint8_t track, 
                            uint16_t secs, uint8_t playbackStatus){
  uint64_t play = (uint64_t) PLAYBACK_STATUS;//0xE90000000000000ull;
  //Serial.print((long unsigned int)(message >> 32), HEX);
  //Serial.println((long unsigned int) message, HEX);
  
  switch(playbackStatus & PBSTATUS_MASK){
    case(STOPPED):
      play |= (uint64_t)PBSTATUS_STOPPED;
      break;
    case(PAUSED):
      play |= (uint64_t)PBSTATUS_PAUSED;
      break;
    case(PLAYING):
      play |= (uint64_t)PBSTATUS_PLAYING; //0x004000000000001ull;
      break;
    default:
      break;
  }
  
  //if( playbackStatus & SHUFFLE_MASK ) play |= PBSTATUS_SHUFFLE;
  //if( playbackStatus & REPEAT_ONE)    play |= PBSTATUS_REPEAT_ONE;
  //if( playbackStatus & REPEAT_ALL)    play |= PBSTATUS_REPEAT_ALL;
  
  play |= (uint64_t)BCD(track)<<(10*4);
  play |= (uint64_t)BCD(disc)<<(8*4);
  play |= (uint64_t)BCD(secs/60)<<(6*4);
  play |= (uint64_t)BCD(secs%60)<<(4*4);

  send(play);
}

void MBus::sendChangedCD(uint8_t CD,uint8_t Track){
  uint64_t play=0xEB900000001ull;
  play|=(uint64_t)CD<<(7*4);
  play|=(uint64_t)BCD(Track)<<(5*4);
  //play|=(uint64_t)(Track/10)<<(6*4);
  send(play);
}

void MBus::sendCDStatus(uint8_t CD){
  uint64_t play=0xEC001999999Full;
  play|=(uint64_t)CD<<(9*4);
  send(play);
}

//convert a byte with a decimal value less than 100 into two binary-coded hex digits
// 49 (0x31) -> 0x49
uint64_t MBus::BCD(uint8_t val){
  uint64_t bcd = 0;
  bcd |= (val/10)<<4;  //tens
  bcd |= (val%10);     //ones
  return bcd;
}

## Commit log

2013-08-14 initital commit, working basic aux-in.
    ipod controls still not working; may be wiring.
    [MBus.cpp, pseudochanger.ino]
2014-06-24 Added optional debugging, tweaked iPod interface
    DEBUG_MODE flag toggles Serial print statements
    tweaks made to AdvancedRemote callbacks for better clarity in variables
    iPod interface still not working, likely a hardware problem.
    [pseudochanger.ino]
2014-07-21 reorganized project
    added EAGLE board files
    updated keywords.txt
    split off Arduino library from project
    reorganized defines
    [electrical_diagram.brd, electrical_diagram.sch, electricals_3.5mm_only.sch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]
2014-09-26 Added v2.6 - smaller, 0603 passives, QFN mega*U4
    Files edited with EAGLE 7.1.0
    Split off v2.6
    - board about .25” shorter
    - 0603 passives
    - QFN package ATMega*U4
    - rearranged power supply
    - tweaked iPod connector board
    [electricals_with_iPod_v2.6.brd, electricals_with_iPod_v2.6.sch]
2014-12-06 iPod breakout split from v2.6, new single-input board
    The iPod connector board was pulled from V2.6 to send to OSHPark
    v2.6 is pending revisions down from the ATMega 16U4 to [8|16|32]U2. May
    shrink more.
    A new board is in the works that can fit on the back of the stereo
    connector, providing only an auxiliary input. Uses an ATTiny.
    [electricals_with_iPod_v2.6.brd, electricals_with_iPod_v2.6.sch, iPod_BoB.brd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]
2015-01-19 Updated aux-only board, preparing to switch to 32/16/8U2
    [electricals_with_iPod_v2.6.brd, electricals_with_iPod_v2.6.sch, on-connector PCB.brd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]

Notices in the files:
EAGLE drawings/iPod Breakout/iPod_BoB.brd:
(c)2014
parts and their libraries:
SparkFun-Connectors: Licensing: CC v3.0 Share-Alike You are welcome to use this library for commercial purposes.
